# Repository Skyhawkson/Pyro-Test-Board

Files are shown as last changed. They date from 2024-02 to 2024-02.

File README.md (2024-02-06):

# Pyro-Test-Board
An analog, high-current pyrotechnic driver for evaluating high power rocketry igniters

pyro-test-board

This board is intended to evaluate igniters and other pyrotechnic devices used in high-power rocketry for safe parachute ejection. It uses closed-loop analog current control to drive a set current through a device of varying resistance while allowing for external measurements of the test device's performance. It is intended for benchtop use with a 3S or 4S LiPo battery, or a benchtop power supply. 

More information can be found in the [Schematic](https://github.com/Skyhawkson/Pyro-Test-Board/blob/main/Pyro%20Tester%20Rev1.0.0/Pyro%20Test%20Board.pdf) or the [KiCAD 7+ Project Files](https://github.com/Skyhawkson/Pyro-Test-Board/tree/main/Pyro%20Tester%20Rev1.0.0/Pyro%20Test%20Board%20Rev1.0.0).
SPICE simulation data is located in the [SPICE Sims](https://github.com/Skyhawkson/Pyro-Test-Board/tree/main/Pyro%20Tester%20Rev1.0.0/SPICE%20Sims) folder.

download

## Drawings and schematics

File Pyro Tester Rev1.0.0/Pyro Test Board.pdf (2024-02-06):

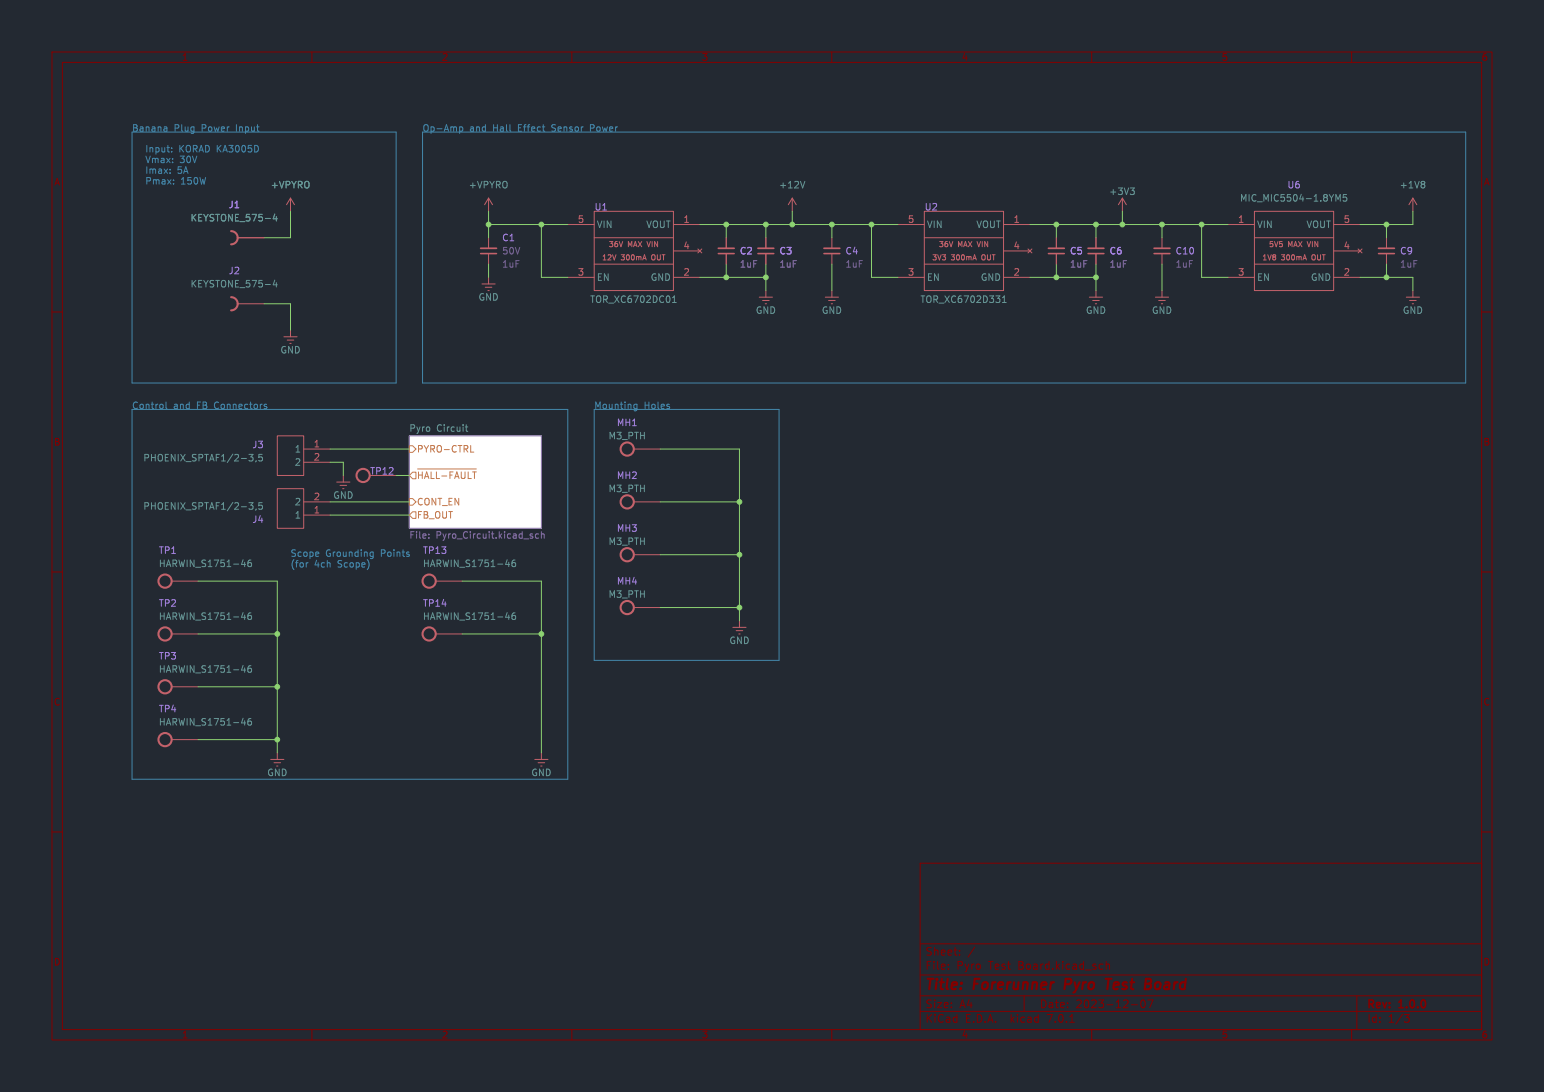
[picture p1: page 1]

1uF Mounting Holes Scope Grounding Points

Id: 1/3 Title: Forerunner Pyro Test Board

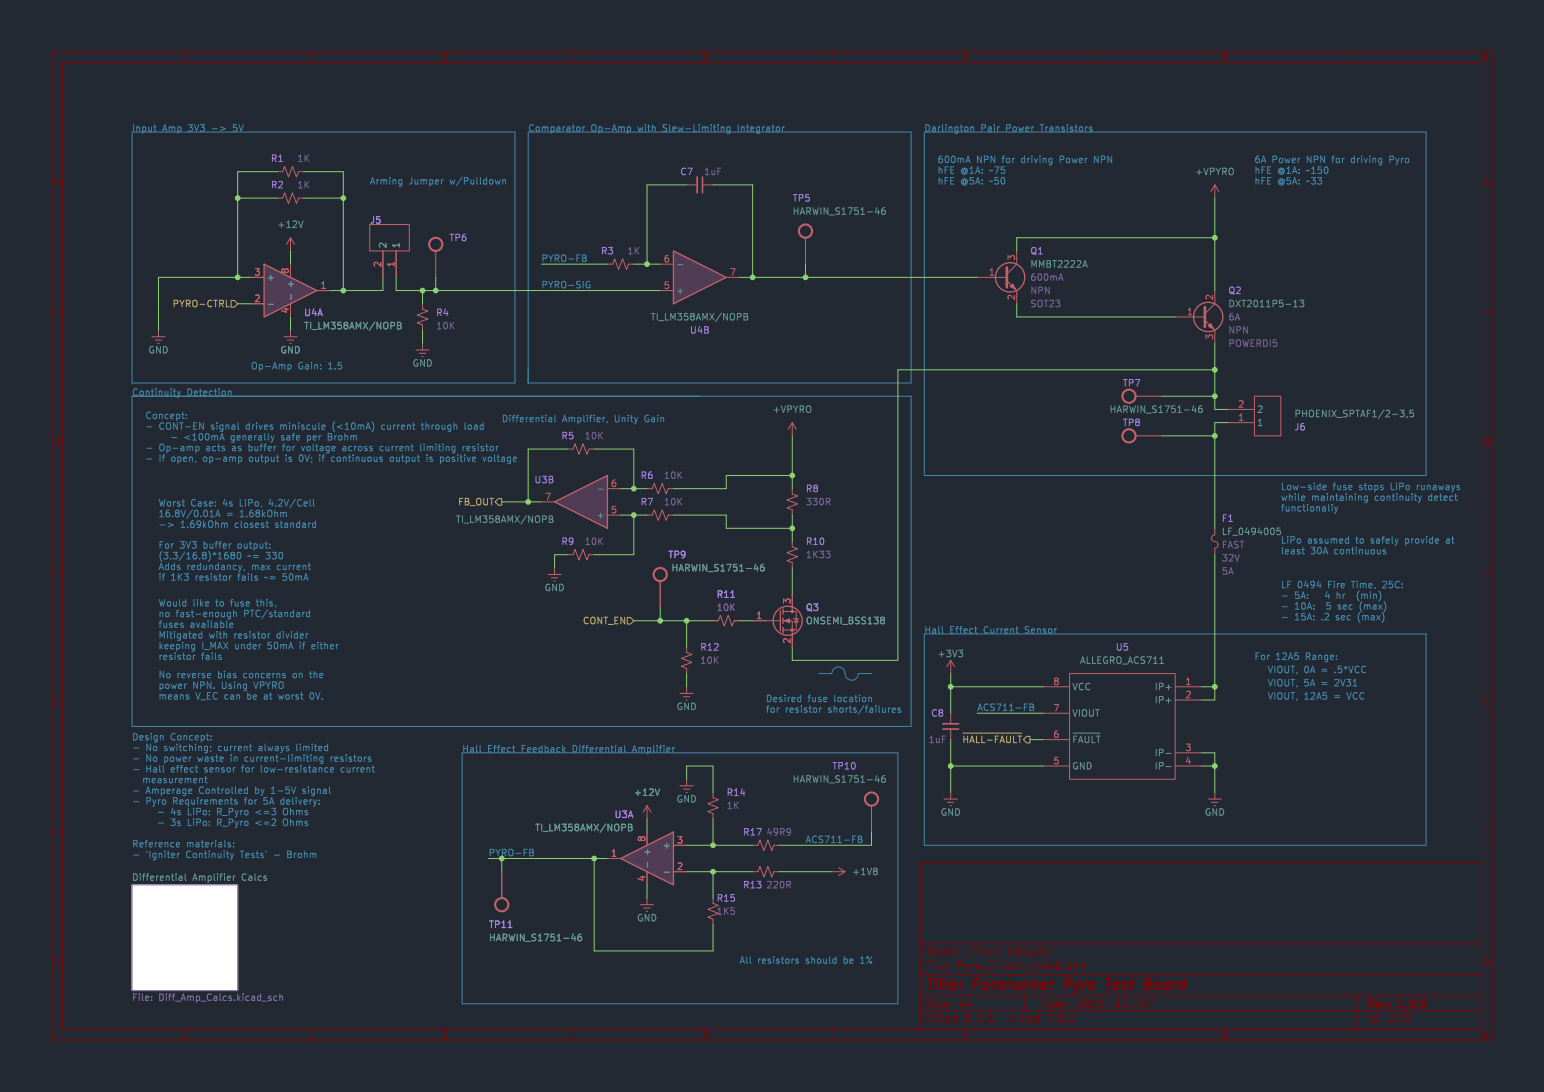
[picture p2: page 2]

6A Power NPN for driving Pyro
hFE @1A: ~150
hFE @5A: ~33 For 12A5 Range:

functionaliy LiPo assumed to safely provide at

Id: 2/3 Title: Forerunner Pyro Test Board

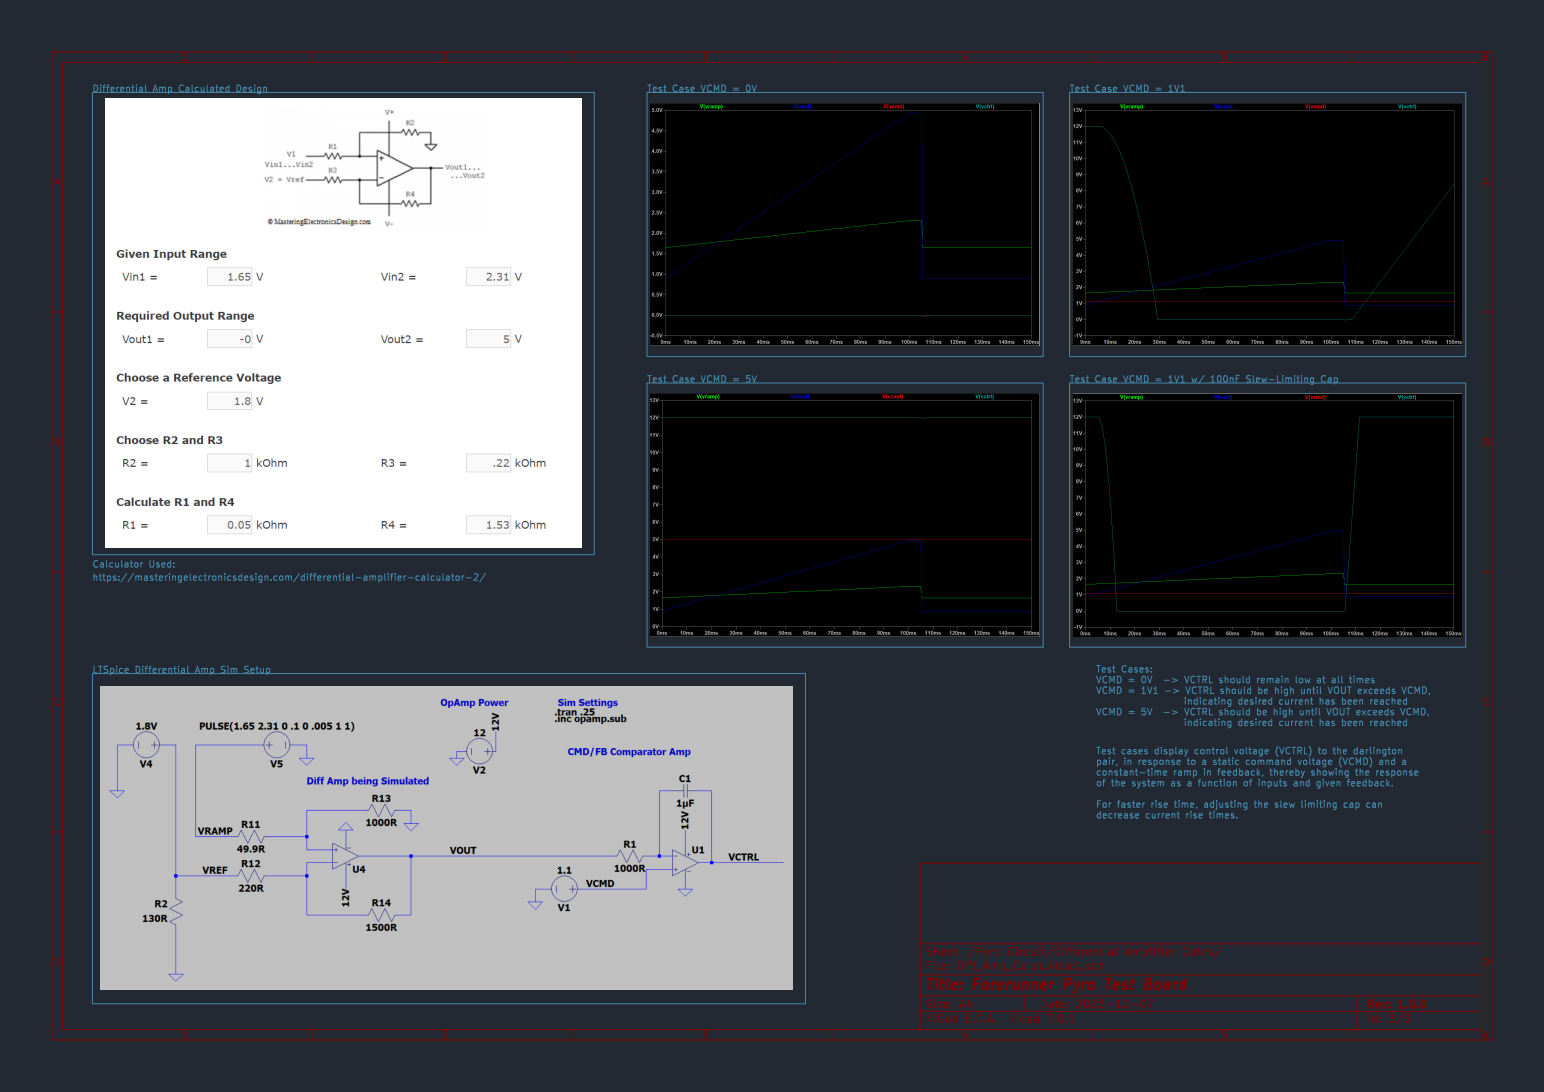
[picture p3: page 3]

https://masteringelectronicsdesign.com/differential-amplifier-calculator-2/

pair, in response to a static command voltage (VCMD) and a

decrease current rise times.

Id: 3/3 Title: Forerunner Pyro Test Board

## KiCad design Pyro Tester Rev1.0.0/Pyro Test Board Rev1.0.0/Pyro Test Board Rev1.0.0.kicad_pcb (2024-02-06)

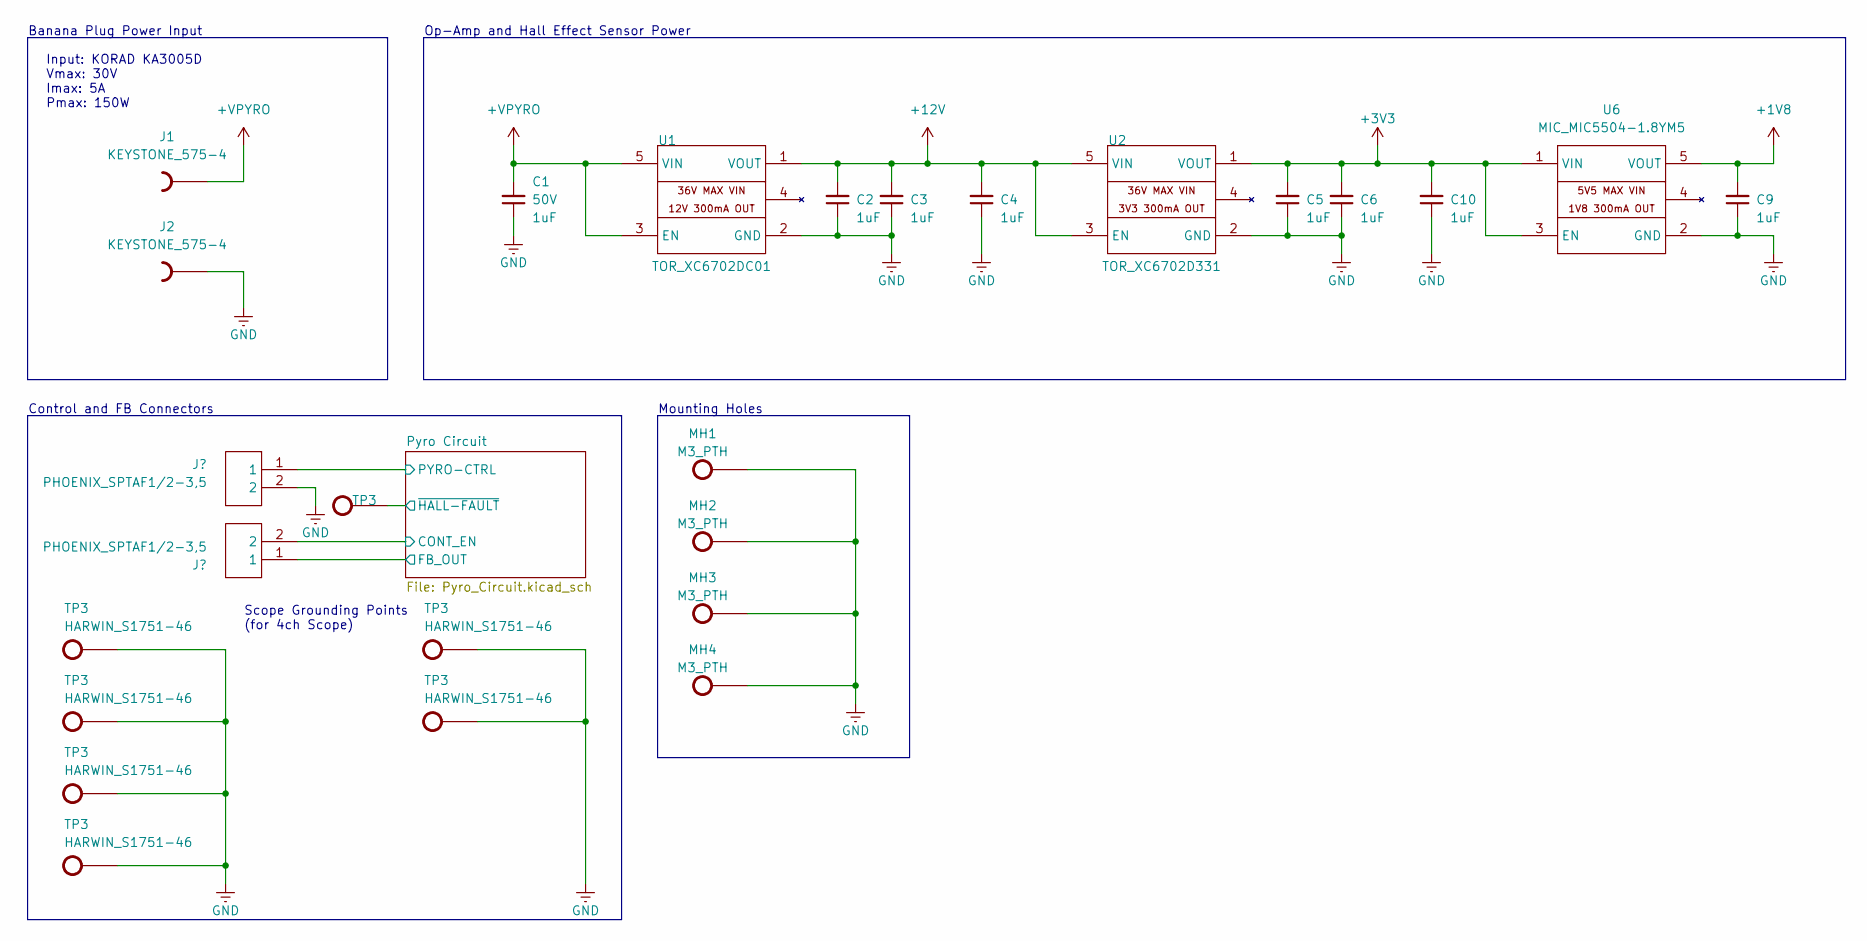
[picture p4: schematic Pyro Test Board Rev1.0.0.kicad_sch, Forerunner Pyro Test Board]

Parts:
C1, C2, C3, C4, C5, C6, C9, C10: 1UF_0805; GENERIC_0805_CAP; Tolerance 10%; Rating 50V
J1, J2: KEYSTONE_575-4
J3, J4: PHOENIX_SPTAF1/2-3,5; PHOENIX_SPTAF1_2-3,5
MH1, MH2, MH3, MH4: M3_PTH; GENERIC_MH_M3
TP3: HARWIN_S1751-46; HARWIN_S1751-XX
U1: TOR_XC6702DC01; TOR_SOT-89-5
U2: TOR_XC6702D331; TOR_SOT-89-5
U6: MIC_MIC5504-1.8YM5; MIC_SOT23-5LD-PL-1

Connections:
+1V8: C9.2, U6.5 (VOUT); also elsewhere on the board
+3V3: C5.2, C6.2, C10.2, U2.1 (VOUT), U6.1 (VIN), U6.3 (EN); also elsewhere on the board
+12V: C2.2, C3.2, C4.2, U1.1 (VOUT), U2.3 (EN), U2.5 (VIN); also elsewhere on the board
+VPYRO: C1.2, J1.1, U1.3 (EN), U1.5 (VIN); also elsewhere on the board
/Pyro Circuit/CONT_EN: J4.2, J4.2B; also elsewhere on the board
/Pyro Circuit/FB_OUT: J4.1, J4.1B; also elsewhere on the board
/Pyro Circuit/PYRO-CTRL: J3.1, J3.1B; also elsewhere on the board
GND: C1.1, C2.1, C3.1, C4.1, C5.1, C6.1, C9.1, C10.1, J2.1, J3.2, J3.2B, MH1.1, MH2.1, MH3.1, MH4.1, TP3.1, U1.2 (GND), U2.2 (GND), U6.2 (GND); also elsewhere on the board

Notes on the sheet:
Scope Grounding Points (for 4ch Scope)
Input: KORAD KA3005D Vmax: 30V Imax: 5A Pmax: 150W
Control and FB Connectors
Mounting Holes
Op-Amp and Hall Effect Sensor Power
Banana Plug Power Input

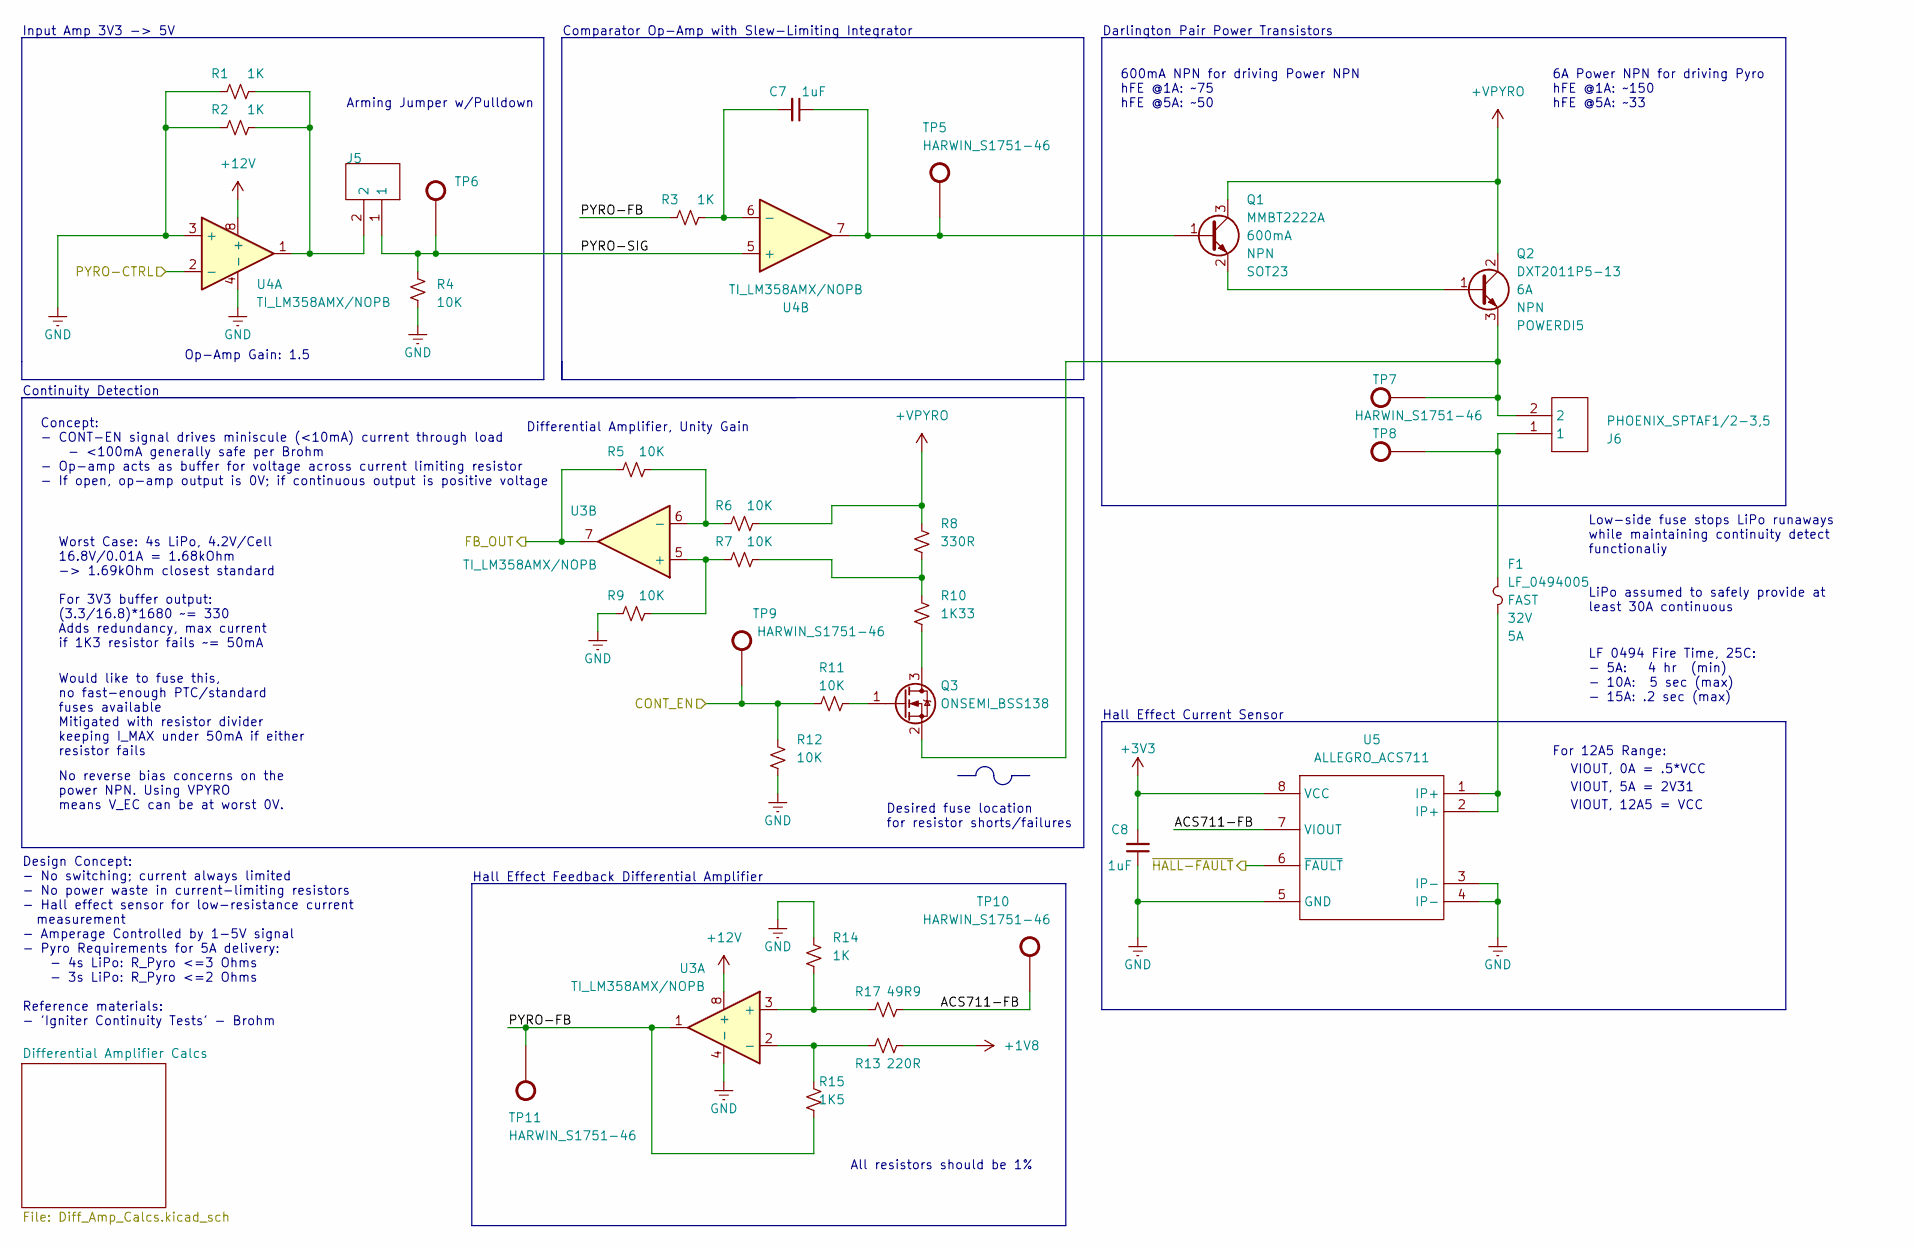
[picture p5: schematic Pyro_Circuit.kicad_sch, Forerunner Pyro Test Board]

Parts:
C7, C8: 1UF_0805; GENERIC_0805_CAP; Tolerance 10%; Rating 50V
F1: LF_0494005; LF_0494_(0603); VOLTAGE 32V
J5, J6: PHOENIX_SPTAF1/2-3,5; PHOENIX_SPTAF1_2-3,5
Q1: MMBT2222A; GENERIC_SOT-23
Q2: DXT2011P5-13; DIODES_POWERDI5
Q3: ONSEMI_BSS138; GENERIC_SOT-23
R1, R2, R3: 1K_0603; GENERIC_0603_RES; Tolerance 1%
R4, R5, R6, R7, R9, R11, R12: 10K_0603; GENERIC_0603_RES; Tolerance 1%
R8, R10: 1K33_0603; GENERIC_0603_RES; Tolerance 1%
R13: 220R_0603; GENERIC_0603_RES; Tolerance 1%
R14: 2K2_0603; GENERIC_0603_RES; Tolerance 5%
R15: 0R_0603; GENERIC_0603_RES; Tolerance 1%
R17: 49R9_0603; GENERIC_0603_RES; Tolerance 1%
TP5, TP6, TP7, TP8, TP9, TP10, TP11: HARWIN_S1751-46; HARWIN_S1751-XX
U3, U4: TI_LM358AMX/NOPB; TI_D0008A_(SOIC-8)
U5: ALLEGRO_ACS711; ALLEGRO_LC_(SOIC-8)

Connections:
+1V8: R13.2; also elsewhere on the board
+3V3: C8.2, U5.8 (VCC); also elsewhere on the board
+12V: U3.8 (+), U4.8 (+); also elsewhere on the board
+VPYRO: Q1.3 (C), Q2.2 (C), R6.2, R8.2; also elsewhere on the board
/Pyro Circuit/ACS711-FB: R17.2, TP10.1, U5.7 (VIOUT)
/Pyro Circuit/CONT_EN: R11.2, R12.2, TP9.1; also elsewhere on the board
/Pyro Circuit/FB_OUT: R5.1, U3.7; also elsewhere on the board
/Pyro Circuit/PYRO-CTRL: U4.2 (-); also elsewhere on the board
/Pyro Circuit/PYRO-FB: R3.1, R15.2, TP11.1, U3.1
/Pyro Circuit/PYRO-SIG: J5.1, J5.1B, R4.2, TP6.1, U4.5 (+)
/Pyro Circuit/~HALL-FAULT: U5.6 (~FAULT); also elsewhere on the board
GND: C8.1, R1.1, R2.1, R4.1, R9.1, R12.1, R14.2, U3.4 (-), U4.3 (+), U4.4 (-), U5.3 (IP-), U5.4 (IP-), U5.5 (GND); also elsewhere on the board
unnamed: F1.1, U5.1 (IP+), U5.2 (IP+)
unnamed: F1.2, J6.1, J6.1B, TP8.1
unnamed: J5.2, J5.2B, R1.2, R2.2, U4.1
unnamed: C7.1, Q1.1 (B), TP5.1, U4.7
unnamed: Q1.2 (E), Q2.1 (B)
unnamed: J6.2, J6.2B, Q2.3 (E), Q3.2 (S), TP7.1
unnamed: Q3.3 (D), R10.1
unnamed: Q3.1 (G), R11.1
unnamed: R7.2, R8.1, R10.2
unnamed: R13.1, R15.1, U3.2 (-)
unnamed: R14.1, R17.1, U3.3 (+)
unnamed: R7.1, R9.2, U3.5 (+)
unnamed: R5.2, R6.1, U3.6 (-)
unnamed: C7.2, R3.2, U4.6 (-)

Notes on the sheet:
Hall Effect Current Sensor
All resistors should be 1%
600mA NPN for driving Power NPN hFE @1A: ~75 hFE @5A: ~50
Differential Amplifier, Unity Gain
Arming Jumper w/Pulldown
Would like to fuse this, no fast-enough PTC/standard fuses available Mitigated with resistor divider keeping I_MAX under 50mA if either resistor fails
Design Concept: - No switching; current always limited - No power waste in current-limiting resistors - Hall effect sensor for low-resistance current measurement - Amperage Controlled by 1-5V signal - Pyro Requirements for 5A delivery: - 4s LiPo: R_Pyro <=3 Ohms - 3s LiPo: R_Pyro <=2 Ohms Reference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
For 12A5 Range:
VIOUT, 5A = 2V31
6A Power NPN for driving Pyro hFE @1A: ~150 hFE @5A: ~33
Desired fuse location for resistor shorts/failures
Worst Case: 4s LiPo, 4.2V/Cell 16.8V/0.01A = 1.68kOhm -> 1.69kOhm closest standard
VIOUT, 12A5 = VCC
Darlington Pair Power Transistors
Continuity Detection
LF 0494 Fire Time, 25C: - 5A: 4 hr (min) - 10A: 5 sec (max) - 15A: .2 sec (max)
Comparator Op-Amp with Slew-Limiting Integrator
No reverse bias concerns on the power NPN. Using VPYRO means V_EC can be at worst 0V.
For 3V3 buffer output: (3.3/16.8)*1680 ~= 330 Adds redundancy, max current if 1K3 resistor fails ~= 50mA
Low-side fuse stops LiPo runaways while maintaining continuity detect functionaliy LiPo assumed to safely provide at least 30A continuous
Input Amp 3V3 -> 5V
Op-Amp Gain: 1.5
Concept: - CONT-EN signal drives miniscule (<10mA) current through load - <100mA generally safe per Brohm - Op-amp acts as buffer for voltage across current limiting resistor - If open, op-amp output is 0V; if continuous output is positive voltage
Hall Effect Feedback Differential Amplifier
VIOUT, 0A = .5*VCC

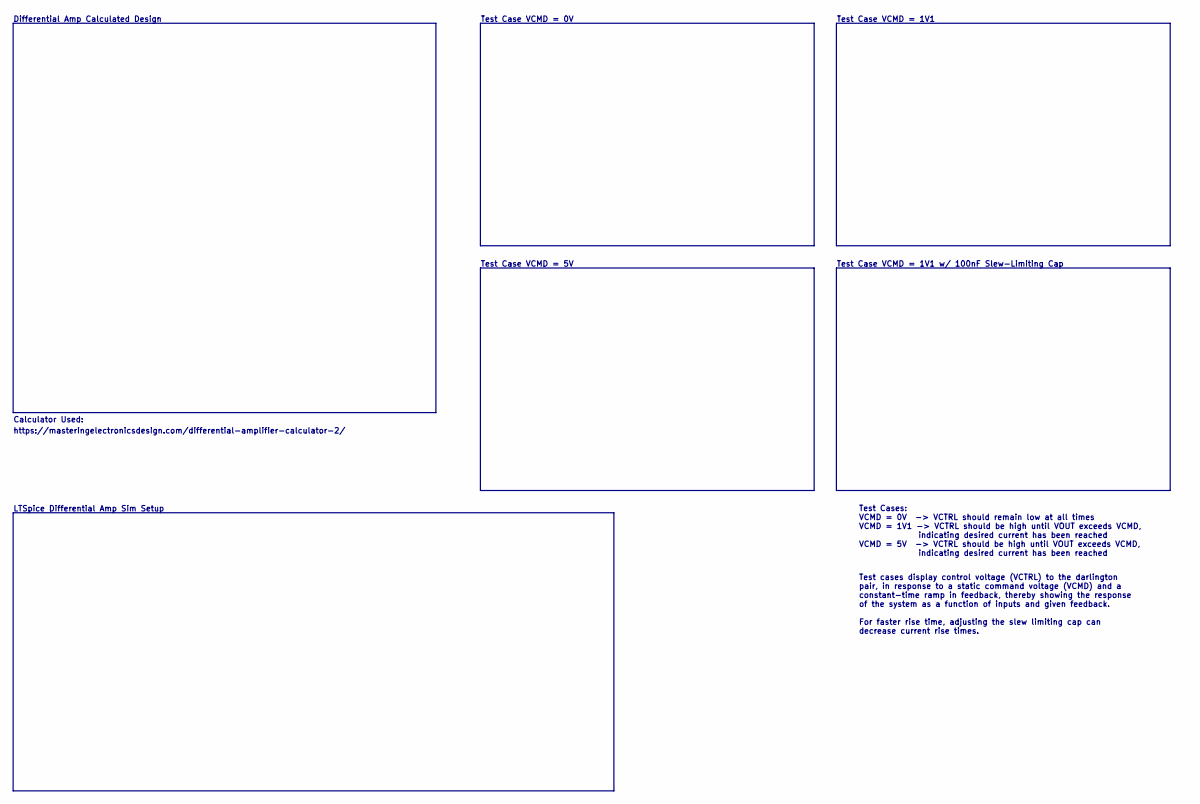
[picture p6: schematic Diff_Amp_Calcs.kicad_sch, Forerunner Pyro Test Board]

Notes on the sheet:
Test Case VCMD = 1V1
Test Case VCMD = 1V1 w/ 100nF Slew-Limiting Cap
Test Cases: VCMD = 0V -> VCTRL should remain low at all times VCMD = 1V1 -> VCTRL should be high until VOUT exceeds VCMD, indicating desired current has been reached VCMD = 5V -> VCTRL should be high until VOUT exceeds VCMD, indicating desired current has been reached
Test Case VCMD = 5V
Calculator Used:
Test Case VCMD = 0V
Differential Amp Calculated Design
https://masteringelectronicsdesign.com/differential-amplifier-calculator-2/
LTSpice Differential Amp Sim Setup
Test cases display control voltage (VCTRL) to the darlington pair, in response to a static command voltage (VCMD) and a constant-time ramp in feedback, thereby showing the response of the system as a function of inputs and given feedback. For faster rise time, adjusting the slew limiting cap can de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

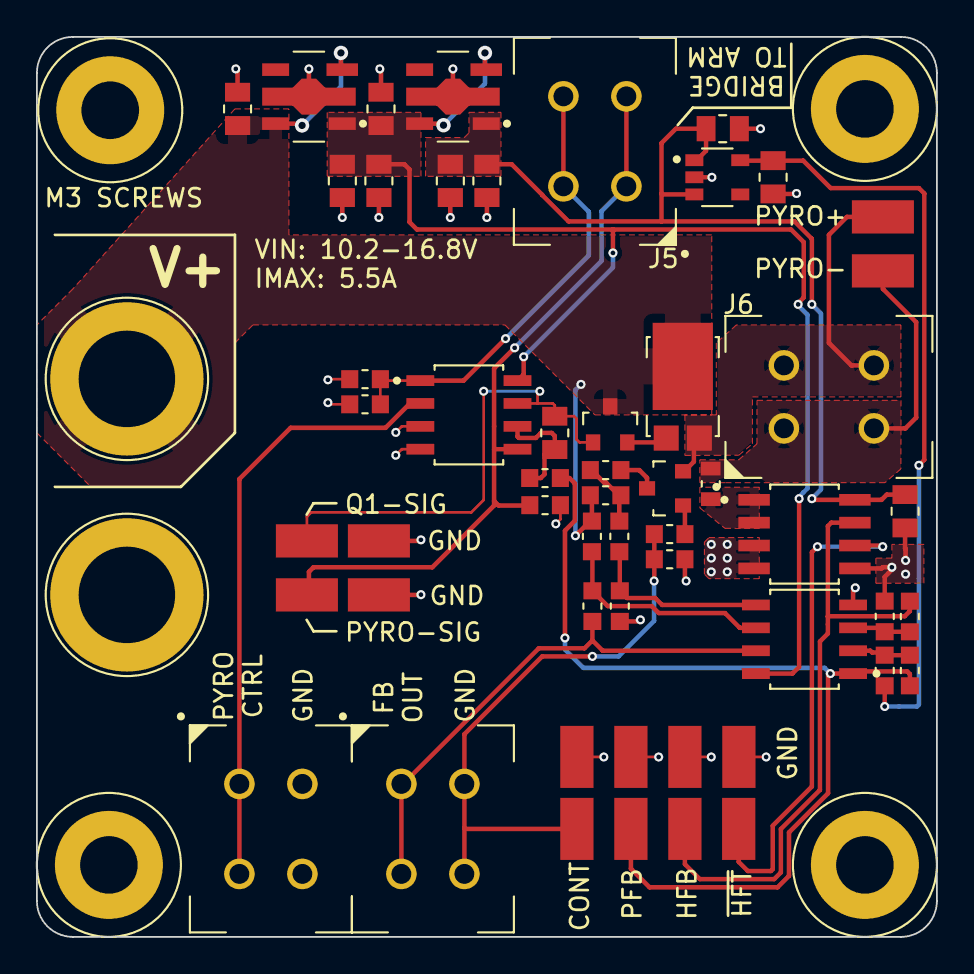
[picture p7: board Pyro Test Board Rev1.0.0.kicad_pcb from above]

Board: 2 copper layers, 50.0 x 50.0 mm, 60 parts (0 on the bottom side), 26 nets.

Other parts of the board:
TP1, TP2, TP4, TP12, TP13, TP14: HARWIN_S1751-46; HARWIN_S1751-XX

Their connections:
/Pyro Circuit/~HALL-FAULT: TP12.1; also elsewhere on the board
GND: TP1.1, TP2.1, TP4.1, TP13.1, TP14.1; also elsewhere on the board
